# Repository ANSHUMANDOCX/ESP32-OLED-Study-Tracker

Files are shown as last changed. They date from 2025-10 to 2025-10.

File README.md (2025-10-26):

# ESP32-OLED-Study-Tracker
Its a Compact Server based study tracker using a OLED display and a ESP32 that help one track their study/work time on particular subjects and also lets use set a target using the interactive web page hosted on the ESP

# Parts used 
- Esp32 Wroom
- 2.42 inch OLED Display
- PCB with onboard programmer

# Features
The system uses Display to set timer and keep track of your productive hours. It also has a webpage hosted on the esp that helps u check on the hours spend at a glance. Also one can set target for the day how much time one needs to be productive for.
It also has a Log system thats logs the time we have spent on something and helps us keep track of how productive one has been. It also has a option to download the log all together as a csv file.

# Images 









# BOM
|Part|Supplier|Cost|LINK|
|----|---|----|----|
|OlED Display|Electronics Comp|$18.9|https://www.electronicscomp.com/waveshare-242inch-oled-display-modulec-12864-resolution-spi-i2c-communication-yellow-display|
|ESP32 WROOM|Electronicscomp|$4.8|https://www.electronicscomp.com/espressif-esp32-wroom-32-16m-128mbit-flash-wifi-bluetooth-module|
|PCB|JLCPCB|$8.64||
|total||$32.5||

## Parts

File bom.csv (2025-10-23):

Designator | Footprint | Quantity | Value | LCSC Part #
C1, C2 | 0603 | 2 | 0.1
C14, C23, C4 | 0603 | 3 | 10uF
C15 | 0603 | 1 | 1uF
C17, C19 | 0603 | 2 | 4.7uf
C18 | 0603 | 1 | 104
C22 | 0603 | 1 | 47uF
D5, D6 | 0805 | 2 | LED
J1 | PinHeader_1x04_P2.54mm_Vertical | 1 | Conn_01x04_Pin
J2 | PinHeader_1x02_P2.54mm_Vertical | 1 | Conn_01x02_Pin
J4 | USB_C_Receptacle_XKB_U262-16XN-4BVC11 | 1 | USB_C_Receptacle_USB2.0_16P
Q2, Q3 | SOT-23 | 2 | SS8050
R1 | 0603 | 1 | 1k
R12, R15 | 0603 | 2 | 0R
R13, R14, R3, R4 | 0603 | 4 | 10K
R16, R17 | 0603 | 2 | 5.1K
R2 | 0603 | 1 | 2.2k
SW1, SW2, SW5 | SW_SPST_CK_RS282G05A3 | 3 | SW_Push
SW3, SW4 | SW_Push_SPST_NO_Alps_SKRK | 2 | SW_Push
U1 | ESP32-WROOM-32D | 1 | ESP32-WROOM-32E
U2 | WCH_QFN-16-1EP_3x3mm_P0.5mm_EP1.8x1.8mm | 1 | CH343P
U4 | SOT-23-5 | 1 | ME6217C33M5G

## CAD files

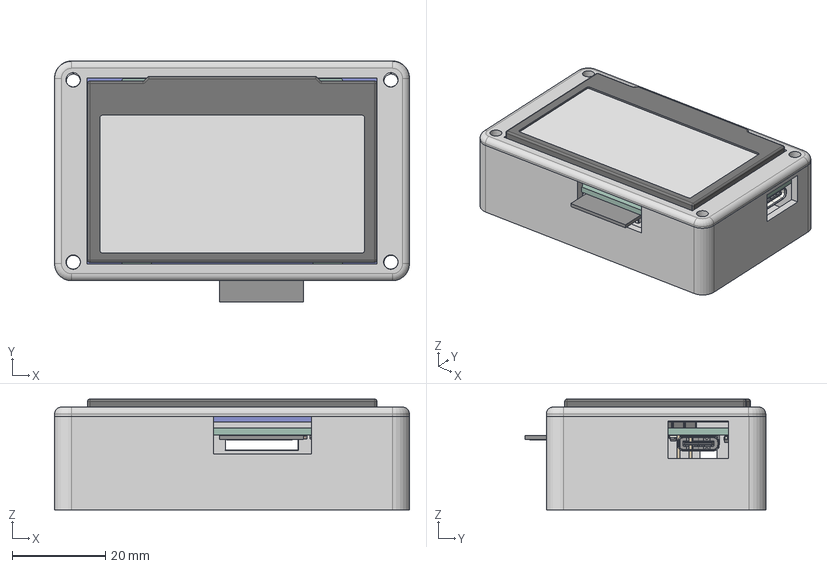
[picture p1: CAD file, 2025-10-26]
CAD/Study Tracker.step
76.0 x 51.6 x 23.7 mm
screen
cable
PLS-7 v2
LED_0805_2012Metric x 2
SOT-23 x 2
USB_C_Receptacle_GCT_USB4105-xx-A_16P_TopMnt_Horizontal
C_0603_1608Metric x 10
R_0603_1608Metric x 10
SW_SPST_CK_RS282G05A3 x 3
PinHeader_1x02_P2.54mm_Vertical
SW_Push_SPST_NO_Alps_SKRK x 2
PinHeader_1x04_P2.54mm_Vertical
ESP32-WROOM-32D-N4
QFN-16 (3x3) Part1
QFN-16 (3x3) Part2 x 16
SOT-23-5
Study Tracker_PCB

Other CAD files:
CAD/BACK v2.f3z
CAD/Front v4.f3z

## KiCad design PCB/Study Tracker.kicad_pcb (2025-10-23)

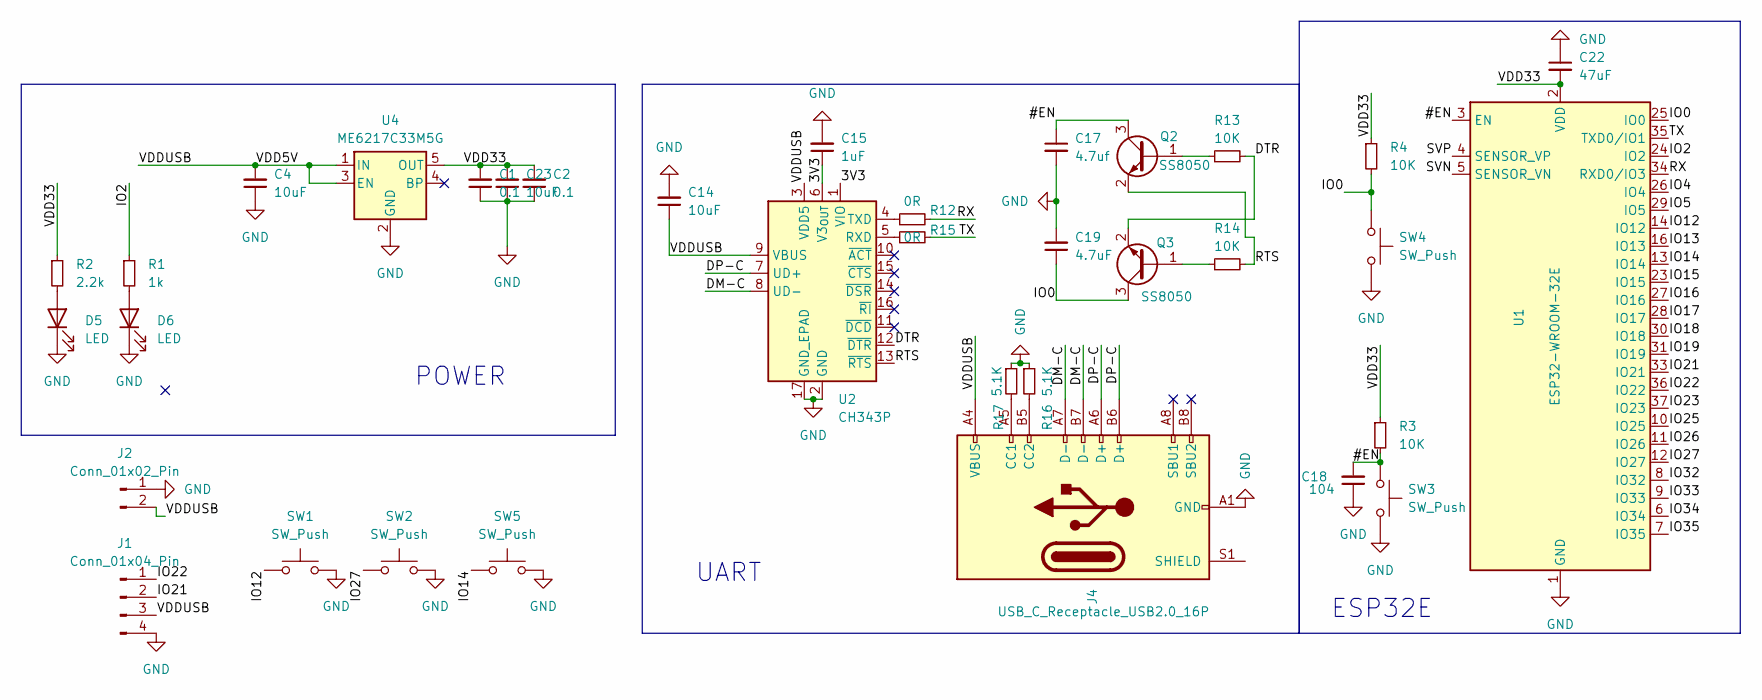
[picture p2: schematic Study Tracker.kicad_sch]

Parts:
C1, C2: 0.1; C_0603_1608Metric_Pad1.08x0.95mm_HandSolder
C4, C14, C23: 10uF; C_0603_1608Metric_Pad1.08x0.95mm_HandSolder
C15: 1uF; C_0603_1608Metric_Pad1.08x0.95mm_HandSolder
C17: 4.7uf; C_0603_1608Metric_Pad1.08x0.95mm_HandSolder
C18: 104; C_0603_1608Metric_Pad1.08x0.95mm_HandSolder
C19: 4.7uF; C_0603_1608Metric_Pad1.08x0.95mm_HandSolder
C22: 47uF; C_0603_1608Metric_Pad1.08x0.95mm_HandSolder
D5, D6: LED; LED_0805_2012Metric_Pad1.15x1.40mm_HandSolder
J1: Conn_01x04_Pin; PinHeader_1x04_P2.54mm_Vertical
J2: Conn_01x02_Pin; PinHeader_1x02_P2.54mm_Vertical
J4: USB_C_Receptacle_USB2.0_16P; USB_C_Receptacle_XKB_U262-16XN-4BVC11
Q2, Q3: SS8050; SOT-23
R1: 1k; R_0603_1608Metric_Pad0.98x0.95mm_HandSolder
R2: 2.2k; R_0603_1608Metric_Pad0.98x0.95mm_HandSolder
R3, R4, R13, R14: 10K; R_0603_1608Metric_Pad0.98x0.95mm_HandSolder
R12, R15: 0R; R_0603_1608Metric_Pad0.98x0.95mm_HandSolder
R16, R17: 5.1K; R_0603_1608Metric_Pad0.98x0.95mm_HandSolder
SW1, SW2, SW5: SW_Push; SW_SPST_CK_RS282G05A3
SW3, SW4: SW_Push; SW_Push_SPST_NO_Alps_SKRK
U1: ESP32-WROOM-32E; ESP32-WROOM-32D
U2: CH343P; WCH_QFN-16-1EP_3x3mm_P0.5mm_EP1.8x1.8mm
U4: ME6217C33M5G; SOT-23-5

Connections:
/3V3: C15.1, U2.1 (VIO), U2.6 (V3_{OUT})
/#EN: C17.1, C18.2, Q2.3 (C), R3.2, SW3.1, U1.3 (EN)
/DM-C: J4.A7 (D-), J4.B7 (D-), U2.8 (UD-)
/DP-C: J4.A6 (D+), J4.B6 (D+), U2.7 (UD+)
/DTR: Q3.2 (E), R13.2, U2.12 (~DTR)
/IO0: C19.1, Q3.3 (C), R4.2, SW4.1, U1.25 (IO0)
/IO2: R1.1, U1.24 (IO2)
/IO4: U1.26 (IO4)
/IO5: U1.29 (IO5)
/IO12: SW1.1, U1.14 (IO12)
/IO13: U1.16 (IO13)
/IO14: SW5.1, U1.13 (IO14)
/IO15: U1.23 (IO15)
/IO16: U1.27 (IO16)
/IO17: U1.28 (IO17)
/IO18: U1.30 (IO18)
/IO19: U1.31 (IO19)
/IO21: J1.2, U1.33 (IO21)
/IO22: J1.1, U1.36 (IO22)
/IO23: U1.37 (IO23)
/IO25: U1.10 (IO25)
/IO26: U1.11 (IO26)
/IO27: SW2.1, U1.12 (IO27)
/IO32: U1.8 (IO32)
/IO33: U1.9 (IO33)
/IO34: U1.6 (IO34)
/IO35: U1.7 (IO35)
/RTS: Q2.2 (E), R14.2, U2.13 (~RTS)
/RX: R12.2, U1.34 (RXD0/IO3)
/SVN: U1.5 (SENSOR_VN)
/SVP: U1.4 (SENSOR_VP)
/TX: R15.2, U1.35 (TXD0/IO1)
/VDD5V: C4.2, C14.1, J1.3, J2.2, J4.A4 (VBUS), J4.A9 (VBUS), J4.B4 (VBUS), J4.B9 (VBUS), U2.3 (VDD5), U2.9 (VBUS), U4.1 (IN), U4.3 (EN)
/VDD33: C1.2, C2.2, C22.2, C23.2, R2.1, R3.1, R4.1, U1.2 (VDD), U4.5 (OUT)
GND: C1.1, C2.1, C4.1, C14.2, C15.2, C17.2, C18.1, C19.2, C22.1, C23.1, D5.1 (K), D6.1 (K), J1.4, J2.1, J4.A1 (GND), J4.A12 (GND), J4.B1 (GND), J4.B12 (GND), R16.1, R17.1, SW1.2, SW2.2, SW3.2, SW4.2, SW5.2, U1.1 (GND), U1.15 (GND), U1.38 (GND), U1.39 (GND), U2.2 (GND), U2.17 (GND_EPAD), U4.2 (GND)
unnamed: D5.2 (A), R2.2
unnamed: D6.2 (A), R1.2
unnamed: J4.A5 (CC1), R17.2
unnamed: J4.B5 (CC2), R16.2
unnamed: Q2.1 (B), R13.1
unnamed: Q3.1 (B), R14.1
unnamed: R15.1, U2.5 (RXD)
unnamed: R12.1, U2.4 (TXD)

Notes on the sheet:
UART
POWER
ESP32E

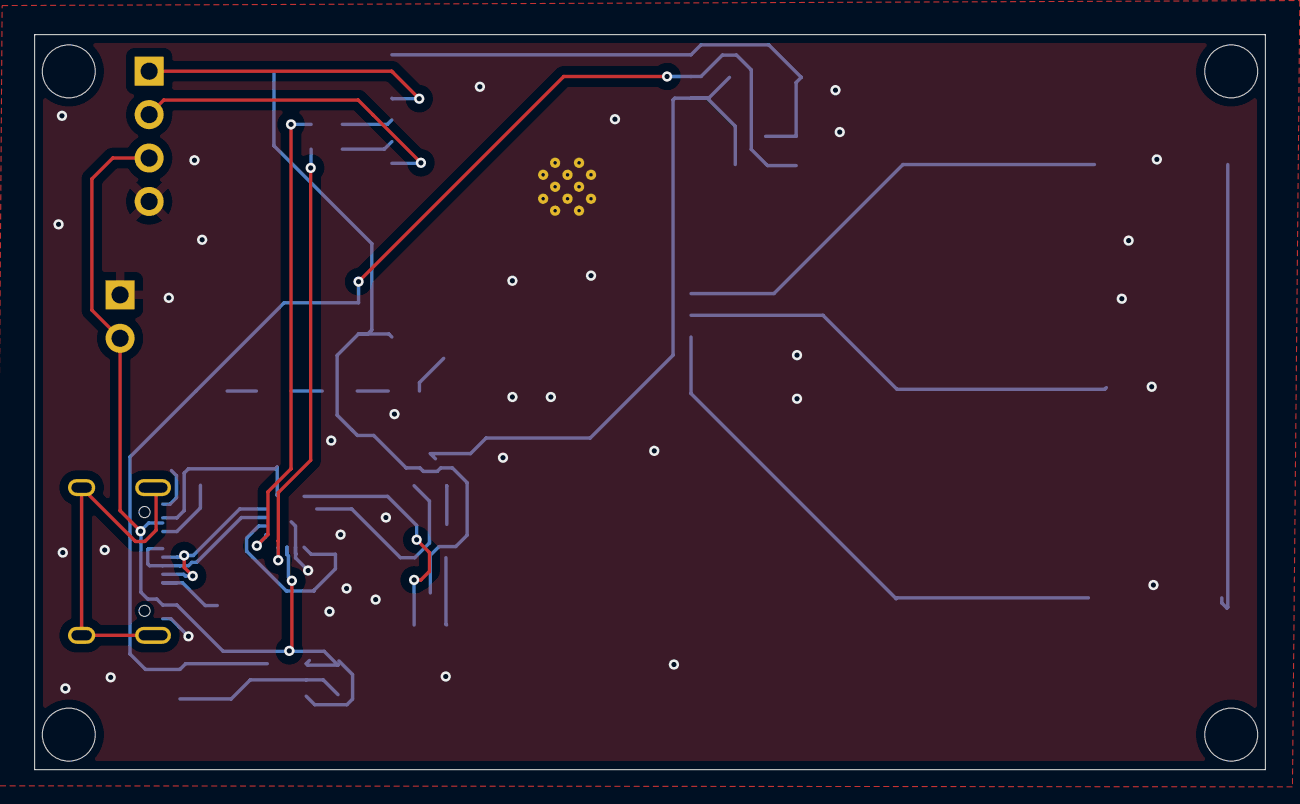
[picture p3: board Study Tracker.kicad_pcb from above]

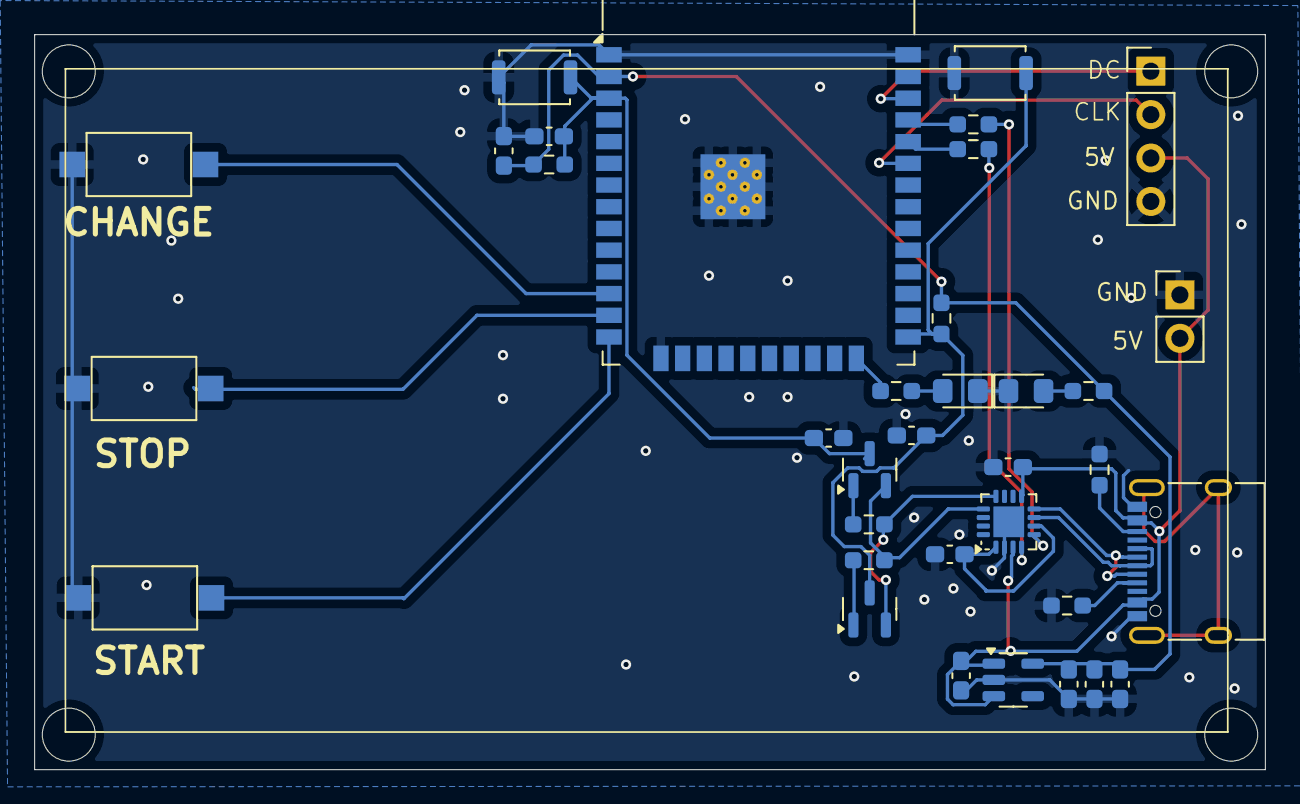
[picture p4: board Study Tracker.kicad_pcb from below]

Board: 2 copper layers, 72.0 x 43.0 mm, 35 parts (35 on the bottom side), 26 nets.

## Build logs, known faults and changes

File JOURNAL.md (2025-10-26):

<!--
  ===================    !!READ THIS NOTICE!!   ====================
  DO NOT edit this file manually. Your changes WILL BE OVERWRITTEN!
  This journal is auto generated and updated by Hack Club Blueprint.
  To edit this file, please edit your journal entries on Blueprint.
  ==================================================================
-->

## 10/21/2025 - Began with researching the parts and finalizing what to use  

I started with researching the components to use with the project how it will. what all it would contain how the webpage will look hosting webpages using esp32 etc.

here are the things finalized

- will be using a 2.42 inch oled display
- ESP32 WROOM module with a onboard programming chip
- TYPE C interface
- like theses 

## 10/22/2025 8 AM - completed the schematic   

Read datasheets of all the components and completed the schematic.
spent a lot of time deciding the uart ic since there are many good choices finally went with CH343.
also, added 3 buttons for changing subject, start/pause, stop. what it will do is that once stop is pressed it will send the the time to the server and sill be available to see through the web page and the pause will just locally pause the timer.  

also added a auto program logic for the esp32 using transistors. 



## 10/22/2025 9 PM - Completed Placing and Routing components on the PCB  

so created a pcb of th size almost similar to the oled display and arranged the components on it.
had to find the exact dimension fo the oled dispaly by goinf through the datasheets.

Also completed the routing of all the components chose to do it on the back side of the pcb and palnning to mount the board directly on the OLED Module using screws to keep the form factor small 

just faced some trouble placing the the screws Holes in proper alignment so that i dont have to modify much after i get the pcb




## 10/23/2025 - Setting up and testing the backend on the esp32  

i tried hosting a webpage on the esp32 with all the feature that i would need. spent the time polishing the website and perfecting those. 
so features i thought of adding-

- a log on the page to keep track of your productive hours
- a target hours options tells one ow much they have been productive and how close they were to their set goal.

here is the website snap


## 10/25/2025 - Started out with the CAD  

made the sketch for the top portion of the housing i cant make it as a single using snce there is a antenna of the ESP always sticking out of the PCB so..

had to go through the datasheet of the OLED to make sure that the Housing size was correct



## 10/26/2025 - made the Bottom and the Upper Portion  

So i found some 27mm m3 screws lying around.
here is what i have planned to do the whole thing will sit on 4 screws and stacking the components.
the screw will go through the Front panel through the PCBs.
the PCB will be held in place with screws. 
then the remaining screw will go all the way to base of the bottom potion where it will be screwed on using heat set inserts added to be base. 






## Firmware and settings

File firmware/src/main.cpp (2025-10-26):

#include <Arduino.h>
#include <Wire.h>
#include <WiFi.h>
#include <WebServer.h>
#include <SPIFFS.h>
#include <Preferences.h>
#include "time.h"
#include <Adafruit_GFX.h>
#include <Adafruit_SSD1306.h>

// ---------------- OLED CONFIG ----------------
#define SCREEN_WIDTH 128
#define SCREEN_HEIGHT 64
#define OLED_RESET    -1
Adafruit_SSD1306 display(SCREEN_WIDTH, SCREEN_HEIGHT, &Wire, OLED_RESET);

// ---------------- BUTTONS ----------------
const int scrollButton = 27;
const int startPauseButton = 12;
const int stopButton = 14;

// ---------------- SUBJECTS ----------------
const char* subjects[] = {"Physics", "Chem", "Maths"};
int subjectIndex = 0;

// ---------------- TIMER VARIABLES ----------------
bool timerRunning = false;
unsigned long startTime = 0;
unsigned long elapsedTime = 0;
unsigned long totalTime[3] = {0, 0, 0};

// Display power management
bool displayOn = true;
unsigned long displayTimeout = 5UL * 60UL * 1000UL;  // 5 min
unsigned long lastActivity = 0;

// ---------------- PREFERENCES ----------------
Preferences prefs;

// ---------------- WIFI + NTP ----------------
const char* ssid = "Airtel_Ashu";
const char* password = "28082005";

IPAddress local_IP(192,168,1,51);
IPAddress gateway(192,168,1,1);
IPAddress subnet(255,255,255,0);
IPAddress primaryDNS(8,8,8,8);
IPAddress secondaryDNS(8,8,4,4);

WebServer server(80);

const char* ntpServer = "pool.ntp.org";
const long gmtOffset_sec = 19800;
const int daylightOffset_sec = 0;

// ---------------- BUTTON DEBOUNCE ----------------
const unsigned long debounceDelay = 80;

bool buttonPressed(int pin) {
  static bool lastState[40];
  static unsigned long lastChange[40];
  bool reading = (digitalRead(pin) == LOW);
  unsigned long now = millis();
  if (reading != lastState[pin] && (now - lastChange[pin] > debounceDelay)) {
    lastChange[pin] = now;
    lastState[pin] = reading;
    if (reading) return true;
  }
  return false;
}

// ---------------- HELPER FUNCTIONS ----------------
String formatTime(unsigned long ms) {
  unsigned long sec = ms / 1000;
  unsigned h = sec / 3600;
  unsigned m = (sec % 3600) / 60;
  unsigned s = sec % 60;
  char buf[9];
  sprintf(buf, "%02u:%02u:%02u", h, m, s);
  return String(buf);
}

void drawScreen() {
  display.clearDisplay();
  display.setTextColor(SSD1306_WHITE);

  // Subject name
  display.setTextSize(2);
  display.setCursor(0, 0);
  display.print(subjects[subjectIndex]);

  // Session timer
  display.setTextSize(1);
  display.setCursor(0, 24);
  display.print("Session:");
  display.setTextSize(2);
  display.setCursor(0, 34);
  display.print(formatTime(elapsedTime));

  // Total time
  display.setTextSize(1);
  display.setCursor(0, 58);
  display.print("Total: ");
  display.print(formatTime(totalTime[subjectIndex]));

  display.display();
}

void updateElapsed() {
  elapsedTime = millis() - startTime;
  drawScreen();
}

// ---------------- DATA SAVE/LOAD ----------------
void saveTotals() {
  prefs.begin("study", false);
  prefs.putULong("phy", totalTime[0]);
  prefs.putULong("chem", totalTime[1]);
  prefs.putULong("math", totalTime[2]);
  prefs.end();
}

void loadTotals() {
  prefs.begin("study", false);
  totalTime[0] = prefs.getULong("phy", 0);
  totalTime[1] = prefs.getULong("chem", 0);
  totalTime[2] = prefs.getULong("math", 0);
  prefs.end();
}

// ---------------- DAILY LOG ----------------
void appendDailyLog() {
  struct tm timeinfo;
  if (!getLocalTime(&timeinfo)) return;

  char datetimeStr[20];
  strftime(datetimeStr, sizeof(datetimeStr), "%Y-%m-%d %H:%M", &timeinfo);

  unsigned long pcm = totalTime[0] + totalTime[1] + totalTime[2];
  File f = SPIFFS.open("/logs.csv", "a");
  if (f) {
    f.printf("%s,%s,%s,%s,%s\n",
             datetimeStr,
             formatTime(totalTime[0]).c_str(),
             formatTime(totalTime[1]).c_str(),
             formatTime(totalTime[2]).c_str(),
             formatTime(pcm).c_str());
    f.close();
  }
  totalTime[0] = totalTime[1] = totalTime[2] = 0;
  saveTotals();
}

// ---------------- SETUP ----------------
void setup() {
#if defined(ARDUINO_XIAO_ESP32C3)
  Wire.begin(4, 5);
#else
  Wire.begin();
#endif

  Serial.begin(115200);
  if (!display.begin(SSD1306_SWITCHCAPVCC, 0x3C)) {
    Serial.println("SSD1306 allocation failed");
    for (;;);
  }
  display.clearDisplay();
  display.display();

  pinMode(scrollButton, INPUT_PULLUP);
  pinMode(startPauseButton, INPUT_PULLUP);
  pinMode(stopButton, INPUT_PULLUP);

  if (!SPIFFS.begin(true)) Serial.println("SPIFFS mount failed");

  if (!SPIFFS.exists("/logs.csv") || SPIFFS.open("/logs.csv", "r").size() == 0) {
    File f = SPIFFS.open("/logs.csv", "w");
    if (f) {
      f.println("Date & Time,Physics,Chemistry,Math,PCM Total");
      f.close();
    }
  }

  loadTotals();

  if (!WiFi.config(local_IP, gateway, subnet, primaryDNS, secondaryDNS))
    Serial.println("Static IP failed");

  WiFi.begin(ssid, password);
  while (WiFi.status() != WL_CONNECTED) {
    delay(500);
    Serial.print(".");
  }
  Serial.println("\nConnected to Wi-Fi");

  configTime(gmtOffset_sec, daylightOffset_sec, ntpServer);

  drawScreen();
  lastActivity = millis();
}

// ---------------- LOOP ----------------
void loop() {
  // Scroll through subjects
  if (!timerRunning && buttonPressed(scrollButton)) {
    subjectIndex = (subjectIndex + 1) % 3;
    elapsedTime = 0;
    lastActivity = millis();
    drawScreen();
  }

  // Start / Pause button
  if (buttonPressed(startPauseButton)) {
    lastActivity = millis();
    if (!timerRunning) {
      startTime = millis() - elapsedTime;
      timerRunning = true;
    } else {
      elapsedTime = millis() - startTime;
      timerRunning = false;
      totalTime[subjectIndex] += elapsedTime;
      saveTotals();
    }
    drawScreen();
  }

  // Stop button
  if (buttonPressed(stopButton)) {
    lastActivity = millis();
    if (timerRunning) {
      elapsedTime = millis() - startTime;
      timerRunning = false;
    }
    totalTime[subjectIndex] += elapsedTime;
    elapsedTime = 0;
    saveTotals();
    drawScreen();
  }

  // Update OLED while running
  if (timerRunning) updateElapsed();

  // Auto turn off OLED after inactivity
  if (displayOn && !timerRunning && (millis() - lastActivity > displayTimeout)) {
    display.ssd1306_command(SSD1306_DISPLAYOFF);
    displayOn = false;
  }

  // Turn OLED back on if button pressed
  if (!displayOn && (digitalRead(scrollButton) == LOW || digitalRead(startPauseButton) == LOW || digitalRead(stopButton) == LOW)) {
    display.ssd1306_command(SSD1306_DISPLAYON);
    displayOn = true;
    lastActivity = millis();
    drawScreen();
  }

  // Daily log at 2 AM
  struct tm timeinfo;
  if (getLocalTime(&timeinfo)) {
    static int lastDay = -1;
    if (timeinfo.tm_hour == 2 && lastDay != timeinfo.tm_mday) {
      appendDailyLog();
      lastDay = timeinfo.tm_mday;
    }
  }

  delay(5);
}
